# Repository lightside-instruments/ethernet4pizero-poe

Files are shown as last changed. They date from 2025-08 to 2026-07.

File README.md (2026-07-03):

```
The ethernet4pizero-poe project is open hardware design of a Raspbery Pi
shield that adds Ethernet over SPI connectivity with the ENC28J60 IC and
Power over Ethernet (POE) capability that can supply 2A at 5V.

The powermod directory contains design of a submodule board to handle DC-DC
conversion. The powermod submodule interface is generic and the
implementation added is based on tps54260. 

The project includes schematics and PCB
design files for KiCAD. The board can be used with
the dtoverlay=enc28j60 option added to /boot/config.txt.

The project is published by Lightside Instruments AS
under TAPR Open Hardware License. Read the LICENSE file
for details.
```
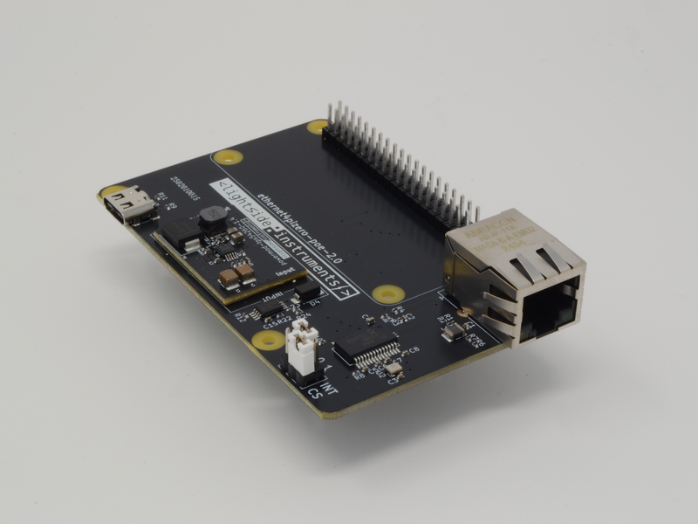
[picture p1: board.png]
board


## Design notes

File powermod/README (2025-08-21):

powermod-tps54260 is a simple DC-DC regulator board
developed by Lightside Instruments AS.

The project includes schematic and PCB
design files for KiCAD.

The project is published by Lightside Instruments AS
under TAPR Open Hardware License. Read the LICENSE file
for details.

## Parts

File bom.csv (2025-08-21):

Reference | Quantity | Identifier | footprint | Value | Tolerance | Voltage | Current | Power | PN
C1, C2, C5, C6, C7, C8, | 6 |  | Capacitor_SMD:C_0402_1005Metric | 100 nF |  |  |  |  | 885012205037
C3, | 1 |  | Capacitor_SMD:C_0402_1005Metric | 0.01uF |  |  |  |  | 885012205012
C4, | 1 |  | Capacitor_SMD:C_0402_1005Metric | 10uF |  |  |  |  | ZRB15XR61A106ME01D
J1, | 1 |  | Connector_PinHeader_2.54mm:PinHeader_2x03_P2.54mm_Vertical | Conn_02x03 |  |  |  |  | TSW-103-23-F-D
J2, | 1 |  | ice4pi:PinSocket_2x20_P2.54mm_Vertical_1_04mm | Raspberry_Pi_2_3 |  |  |  |  | SSQ-120-03-T-D
J3, | 1 |  | Connector_USB:USB_C_Receptacle_GCT_885012205012P_TopMnt_Horizontal | USB_C_Receptacle_USB2.0 |  |  |  |  | USB4105-GF-A
J4, | 1 |  | Connector_RJ:RJ45_Abracon_ARJP11A-MA_Horizontal | Abracon_ARJP11A-MASA-B-A-EMU2 |  |  |  |  | ARJP11A-MASA-B-A-EMU2
L1, | 1 |  | Inductor_SMD:L_1210_3225Metric | L |  |  |  |  | MI1210K600R-10
R1, R2, R3, R4, | 4 |  | Resistor_SMD:R_0402_1005Metric | 50 |  |  |  |  | RC0402JR-0750RL
R5, | 1 |  | Resistor_SMD:R_0402_1005Metric | 0 |  |  |  |  | RC0402JR-100RL
R6, R7, | 2 |  | Resistor_SMD:R_0402_1005Metric | 1K |  |  |  |  | ERJ-2GEJ102X
R8, | 1 |  | Capacitor_SMD:C_0402_1005Metric | 10K |  |  |  |  | ERJ-2GEJ103X
R9, | 1 |  | Resistor_SMD:R_0402_1005Metric | 5.1K |  |  |  |  | ERJ-2RKF5101X
R10, | 1 |  | Resistor_SMD:R_0402_1005Metric | 2.32K |  |  |  |  | ERJ-2RKF2321X
U1, | 1 |  | Package_SO:SSOP-28_5.3x10.2mm_P0.65mm | ENC28J60x-SS |  |  |  |  | ENC28J60x-SS
U2, | 1 |  | Oscillator:Oscillator_SMD_Abracon_ASDMB-4Pin_2.5x2.0mm | DSC1001DE1-025.0000 |  |  |  |  | DSC1001DE1-025.0000

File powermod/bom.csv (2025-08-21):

Reference | Quantity | Identifier | footprint | Value | Tolerance | Voltage | Current | Power | PN
U1 | 1 |  | Package_SO:MSOP-10-1EP_3x3mm_P0.5mm_EP2.2x3.1mm_Mask1.83x1.89mm_ThermalVias | TPS54260 |  |  |  |  | TPS54260DGQR
L1 | 1 |  | Inductor_SMD:L_Taiyo-Yuden_MD-5050 | 15uH |  |  |  |  | SWPA5040S150MT
D1 | 1 |  | Diode_SMD:D_SMC | B360 |  |  |  |  | B360-13-F
R2 | 1 |  | Resistor_SMD:R_0402_1005Metric | 59K |  |  |  |  | ERJ-U02F5902X
R3 | 1 |  | Resistor_SMD:R_0402_1005Metric | 13K |  |  |  |  | ERA-2APB133X
R4 | 1 |  | Capacitor_SMD:C_0402_1005Metric | 332K |  |  |  |  | ERJ-2RKD3323X
R5 | 1 |  | Resistor_SMD:R_0402_1005Metric | 56.2K |  |  |  |  | ERJ-2RKF5622X
R6 | 1 |  | Capacitor_SMD:C_0402_1005Metric | 0K |  |  |  |  | RC0402JR-100RL
R7 | 1 |  | Capacitor_SMD:C_0402_1005Metric | 237K |  |  |  |  | AC0402JR-7W120KL
R8 | 1 |  | Capacitor_SMD:C_0402_1005Metric | 29K |  |  |  |  | RT0402DRD0729K4L
C1;C4 | 1 |  | Capacitor_SMD:C_1210_3225Metric | 10uF |  |  |  |  | GRM32DC72A475KE01L
C2;C5 | 2 |  | Capacitor_SMD:C_0805_2012Metric | 22uF |  |  |  |  | CC0805MKX5R5BB476
C3 | 1 |  | Capacitor_SMD:C_0402_1005Metric | 0.1uF |  |  |  |  | CC0402KRX7R9BB101
C7 | 1 |  | Capacitor_SMD:C_0402_1005Metric | 0.01uF |  |  |  |  | 885012205012
C8 | 1 |  | Capacitor_SMD:C_0402_1005Metric | 4700pF |  |  |  |  | C1005X5R0J475M050BC
C9 | 1 |  | Capacitor_SMD:C_0402_1005Metric | 33pF |  |  |  |  | 885012005077

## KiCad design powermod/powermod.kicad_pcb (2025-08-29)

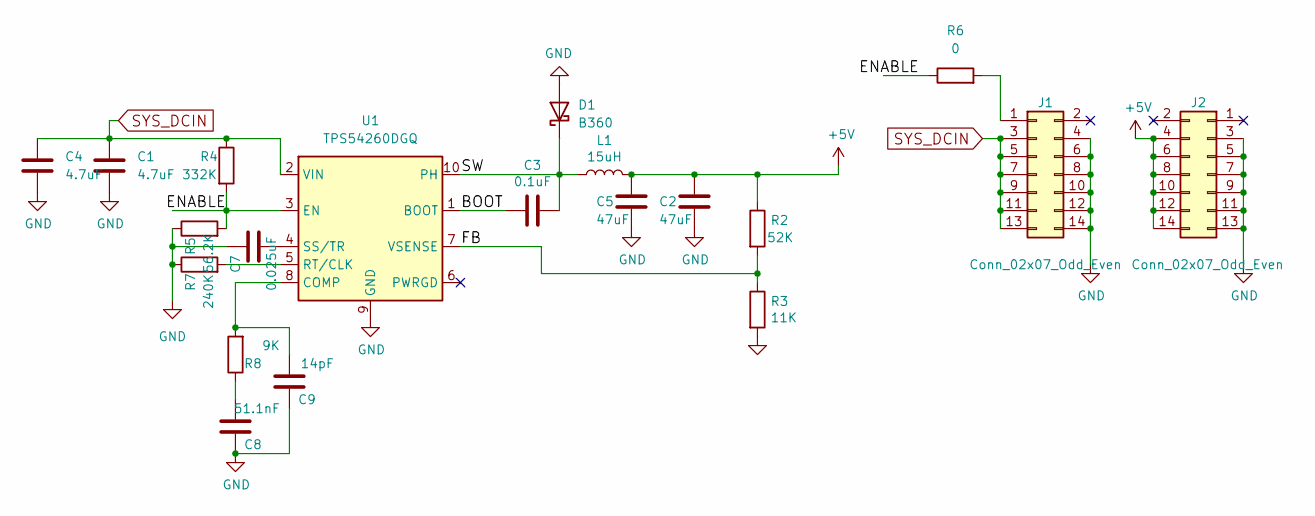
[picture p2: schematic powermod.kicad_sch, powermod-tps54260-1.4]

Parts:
C1, C4: 4.7uF; C_1210_3225Metric
C2, C5: 47uF; C_0805_2012Metric
C3: 0.1uF; C_0402_1005Metric
C7: 0.025uF; C_0402_1005Metric
C8: 51.1nF; C_0402_1005Metric
C9: 14pF; C_0402_1005Metric
D1: B360; D_SMC
J1, J2: Conn_02x07_Odd_Even; PinHeader_2x07_P2.00mm_Vertical_SMD
L1: 15uH; L_Taiyo-Yuden_MD-5050
R2: 52K; R_0402_1005Metric
R3: 11K; R_0402_1005Metric
R4: 332K; R_0402_1005Metric
R5: 56.2K; R_0402_1005Metric
R6: 0; R_0402_1005Metric
R7: 240K; R_0402_1005Metric
R8: 9K; R_0402_1005Metric
U1: TPS54260DGQ; MSOP-10-1EP_3x3mm_P0.5mm_EP2.2x3.1mm_Mask1.83x1.89mm_Therma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

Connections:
+5V: C2.1, C5.1, J2.4, J2.6, J2.8, J2.10, J2.12, J2.14, L1.2, R2.1
/BOOT: C3.2, U1.1 (BOOT)
/ENABLE: R4.2, R5.2, R6.1, U1.3 (EN)
/FB: R2.2, R3.1, U1.7 (VSENSE)
/SW: C3.1, D1.1 (K), L1.1, U1.10 (PH)
GND: C1.2, C2.2, C4.2, C5.2, C7.1, C8.1, C9.1, D1.2 (A), J1.4, J1.6, J1.8, J1.10, J1.12, J1.14, J2.3, J2.5, J2.7, J2.9, J2.11, J2.13, R3.2, R5.1, R7.1, U1.9 (GND), U1.11 (GND)
unnamed: C8.2, R8.1
unnamed: J1.1, R6.2
unnamed: C9.2, R8.2, U1.8 (COMP)
unnamed: R7.2, U1.5 (RT/CLK)
unnamed: C7.2, U1.4 (SS/TR)
SYS_DCIN: C1.1, C4.1, J1.3, J1.5, J1.7, J1.9, J1.11, J1.13, R4.1, U1.2 (VIN)

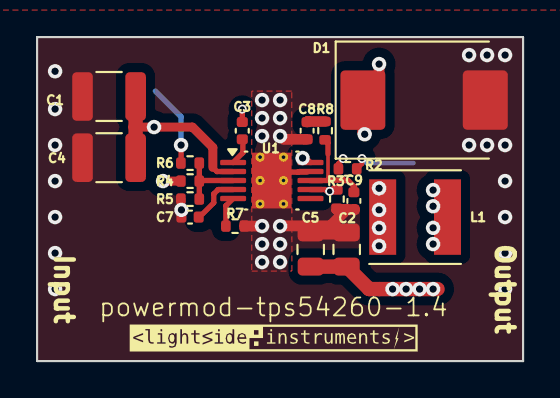
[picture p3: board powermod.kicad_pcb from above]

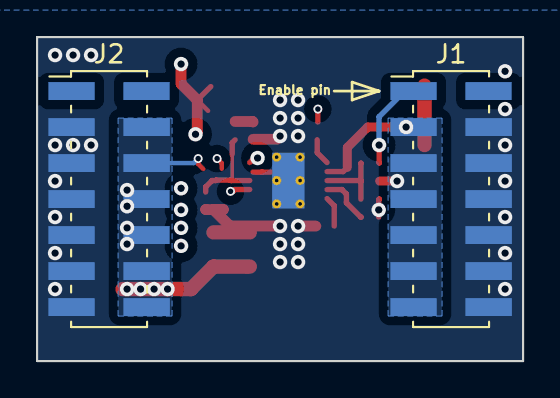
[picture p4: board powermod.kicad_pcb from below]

Board: 4 copper layers, 27.0 x 18.0 mm, 21 parts (2 on the bottom side), 12 nets.

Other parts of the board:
svg2mod: G***; lsi-logo-16mm

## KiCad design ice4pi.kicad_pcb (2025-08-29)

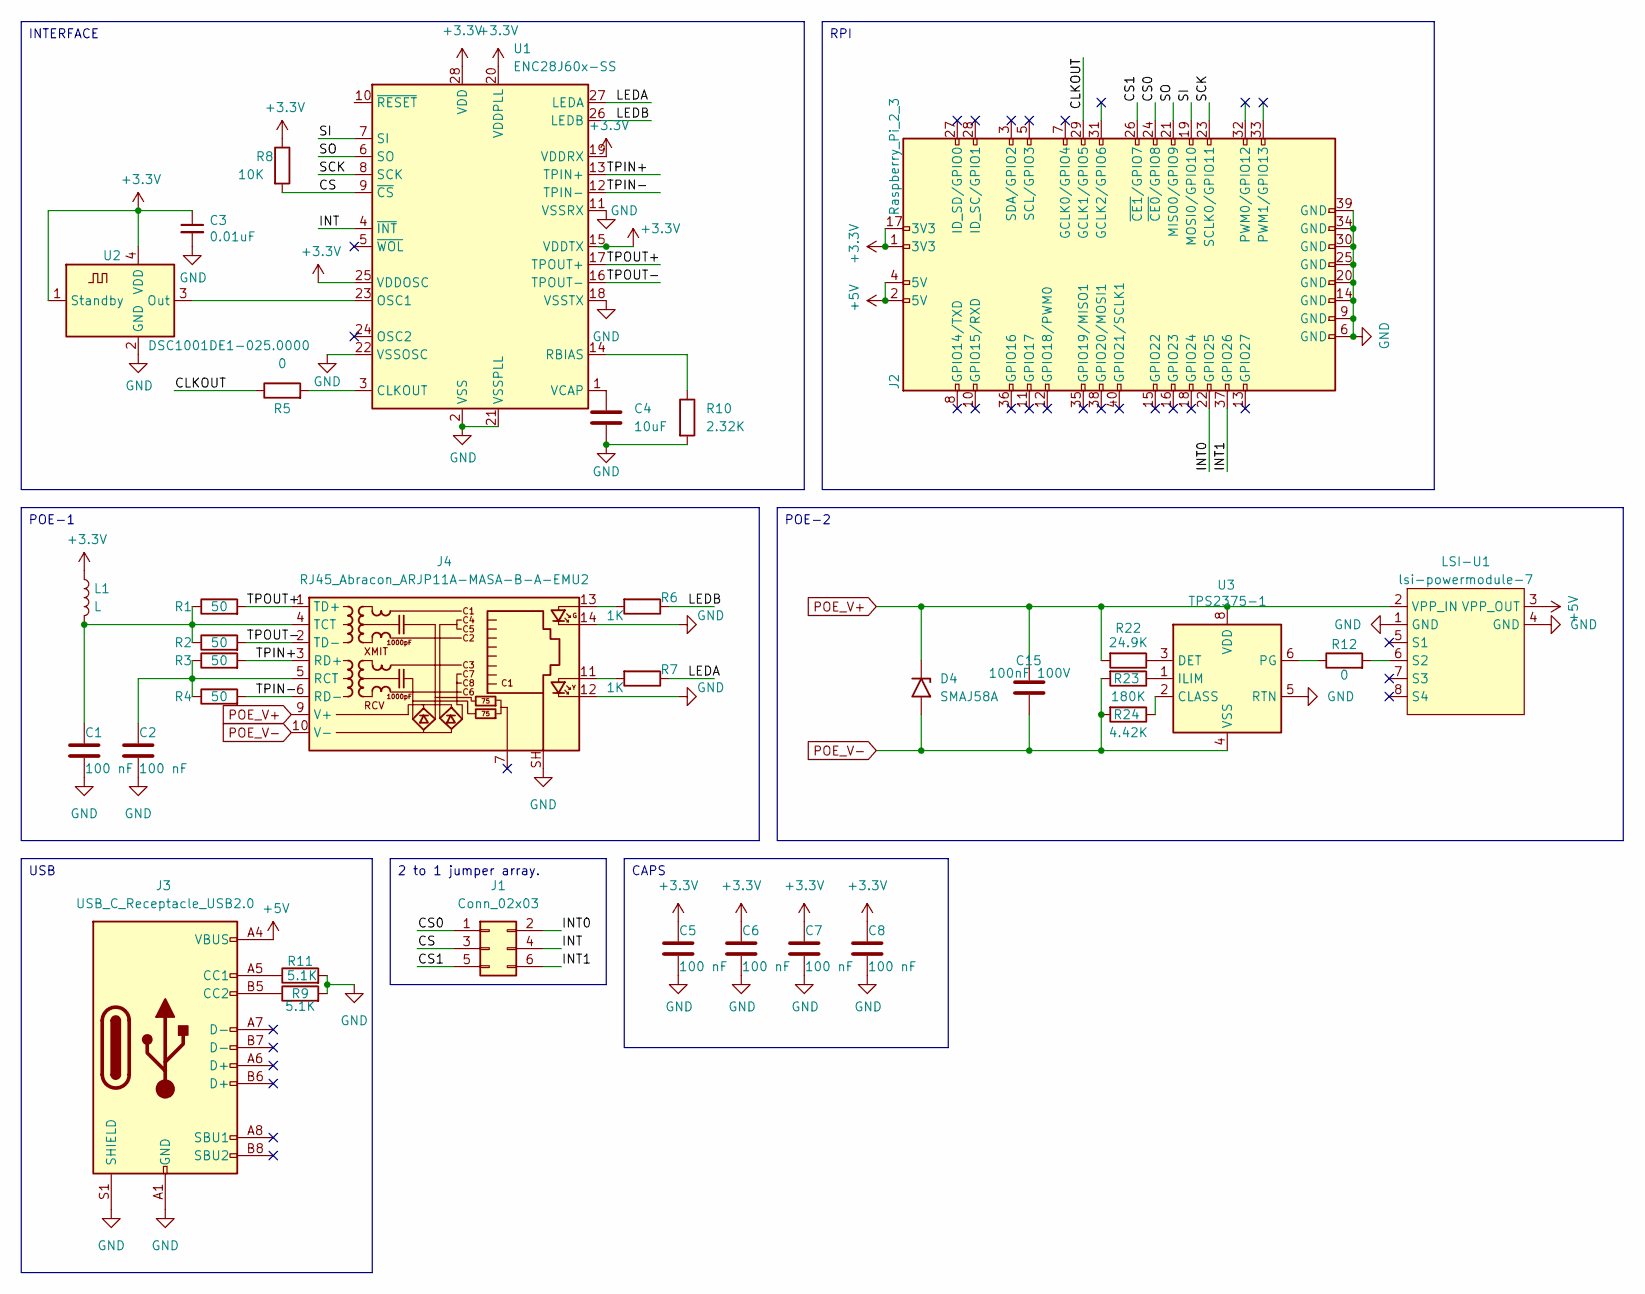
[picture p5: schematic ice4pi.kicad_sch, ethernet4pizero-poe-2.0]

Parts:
C1, C2, C5, C6, C7, C8: 100 nF; C_0402_1005Metric
C3: 0.01uF; C_0402_1005Metric
C4: 10uF; C_0402_1005Metric
C15: 100nF 100V; C_0402_1005Metric
D4: SMAJ58A; D_SMA
J1: Conn_02x03; PinHeader_2x03_P2.54mm_Vertical
J2: Raspberry_Pi_2_3; PinSocket_2x20_P2.54mm_Vertical_1_04mm
J3: USB_C_Receptacle_USB2.0; USB_C_Receptacle_GCT_USB4105-xx-A_16P_TopMnt_Horizontal
J4: RJ45_Abracon_ARJP11A-MASA-B-A-EMU2; RJ45_Abracon_ARJP11A-MA_Horizontal
L1: L; L_1210_3225Metric
LSI-U1: lsi-powermodule-7
R1, R2, R3, R4: 50; R_0402_1005Metric
R5, R12: 0; R_0402_1005Metric
R6, R7: 1K; R_0402_1005Metric
R8: 10K; C_0402_1005Metric
R9, R11: 5.1K; R_0402_1005Metric
R10: 2.32K; R_0402_1005Metric
R22: 24.9K; R_0402_1005Metric
R23: 180K; R_0402_1005Metric
R24: 4.42K; R_0402_1005Metric
U1: ENC28J60x-SS; SSOP-28_5.3x10.2mm_P0.65mm
U2: DSC1001DE1-025.0000; Oscillator_SMD_Abracon_ASDMB-4Pin_2.5x2.0mm
U3: TPS2375-1; TSSOP-8_4.4x3mm_P0.65mm

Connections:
+3.3V: C3.1, C5.1, C6.1, C7.1, C8.1, J2.1 (3V3), J2.17 (3V3), L1.1, R8.1, U1.15 (VDDTX), U1.19 (VDDRX), U1.20 (VDDPLL), U1.25 (VDDOSC), U1.28 (VDD), U2.1 (Standby), U2.4 (VDD)
+5V: J2.2 (5V), J2.4 (5V), J3.A4 (VBUS), J3.A9 (VBUS), J3.B4 (VBUS), J3.B9 (VBUS), LSI-U1.3 (VPP_OUT)
/CLKOUT: J2.29 (GCLK1/GPIO5), R5.1
/CS: J1.3, R8.2, U1.9 (~CS)
/CS0: J1.1, J2.24 (~CE0/GPIO8)
/CS1: J1.5, J2.26 (~CE1/GPIO7)
/INT: J1.4, U1.4 (~INT)
/INT0: J1.2, J2.22 (GPIO25)
/INT1: J1.6, J2.37 (GPIO26)
/LEDA: R7.1, U1.27 (LEDA)
/LEDB: R6.1, U1.26 (LEDB)
/SCK: J2.23 (SCLK0/GPIO11), U1.8 (SCK)
/SI: J2.19 (MOSI0/GPIO10), U1.7 (SI)
/SO: J2.21 (MISO0/GPIO9), U1.6 (SO)
/TPIN+: J4.3 (RD+), R3.2, U1.13 (TPIN+)
/TPIN-: J4.6 (RD-), R4.2, U1.12 (TPIN-)
/TPOUT+: J4.1 (TD+), R1.2, U1.17 (TPOUT+)
/TPOUT-: J4.2 (TD-), R2.2, U1.16 (TPOUT-)
GND: C1.2, C2.2, C3.2, C4.2, C5.2, C6.2, C7.2, C8.2, J2.6 (GND), J2.9 (GND), J2.14 (GND), J2.20 (GND), J2.25 (GND), J2.30 (GND), J2.34 (GND), J2.39 (GND), J3.A1 (GND), J3.A12 (GND), J3.B1 (GND), J3.B12 (GND), J3.S1 (SHIELD), J4.12, J4.14, J4.SH, LSI-U1.1 (GND), LSI-U1.4 (GND), R9.2, R10.2, R11.2, U1.2 (VSS), U1.11 (VSSRX), U1.18 (VSSTX), U1.21 (VSSPLL), U1.22 (VSSOSC), U2.2 (GND), U3.5 (RTN)
unnamed: J3.A5 (CC1), R11.1
unnamed: J3.B5 (CC2), R9.1
unnamed: J4.11, R7.2
unnamed: J4.13, R6.2
unnamed: C2.1, J4.5 (RCT), R3.1, R4.1
unnamed: C1.1, J4.4 (TCT), L1.2, R1.1, R2.1
unnamed: LSI-U1.6 (S2), R12.2
unnamed: R5.2, U1.3 (CLKOUT)
unnamed: U1.23 (OSC1), U2.3 (Out)
unnamed: R10.1, U1.14 (RBIAS)
unnamed: C4.1, U1.1 (VCAP)
unnamed: R24.1, U3.2 (CLASS)
unnamed: R22.1, U3.3 (DET)
unnamed: R23.1, U3.1 (ILIM)
unnamed: R12.1, U3.6 (PG)
POE_V+: C15.1, D4.1 (A1), J4.9 (V+), LSI-U1.2 (VPP_IN), R22.2, U3.8 (VDD)
POE_V-: C15.2, D4.2 (A2), J4.10 (V-), R23.2, R24.2, U3.4 (VSS)

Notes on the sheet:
INTERFACE
RPI
POE-2
CAPS
POE-1
USB
2 to 1 jumper array.

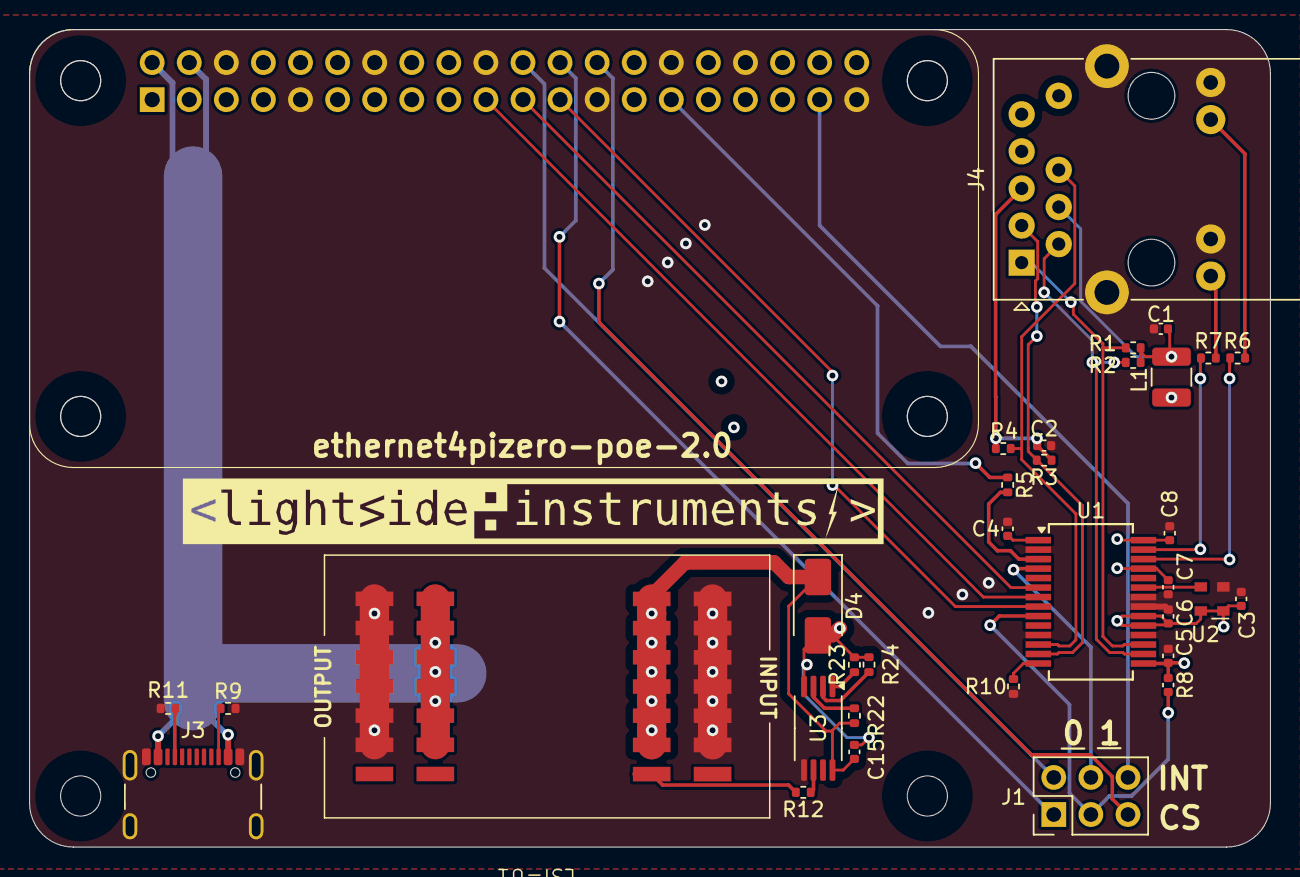
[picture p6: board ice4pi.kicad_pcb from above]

Board: 4 copper layers, 85.0 x 56.0 mm, 35 parts (1 on the bottom side), 36 nets.

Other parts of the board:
svg2mod: G***; lsi-logo-48mm
